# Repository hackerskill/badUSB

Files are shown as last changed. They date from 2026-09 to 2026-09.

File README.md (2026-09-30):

# badUSB
A CH552G powered BadUSB keystroke injection tool that emulates a standard USB keyboard to execute automated payloads.

### A compact usb stick style badUSB based on CH552G.
---
USB stick style device to emulate a keyboard for automating payload execution.

## Features
- CH552G acts as the main microcontroller
- Fast injection speed
- USB A connectivity
- LEDs for visual status and feedback
- Compact USB stick style PCB

---

# Schematics-


# PCB-


## How It Works

1. CH552G emulates a standard keyboard.

2. Depending on code, it either waits for bottom button input or automatically injects the payload coded in it.

3. The upper button in pressed while plugging in to enter programming mode.

# BOM-
| Component Name | Description | Quantity |
| :--- | :--- | :---: |
| **CH552G** | Chipset | 1 |
| **Resistors** | Resistors for Led| 4 |
| **Capacitors** | Capacitors for decoupling | 2 |
| **Leds** | Led for showing status | 3 |
| **Buttons** | Buttons for mode switching | 2 |
| **Custom PCB** | Custom PCB | 1 |

---

**Made by hackerskill**

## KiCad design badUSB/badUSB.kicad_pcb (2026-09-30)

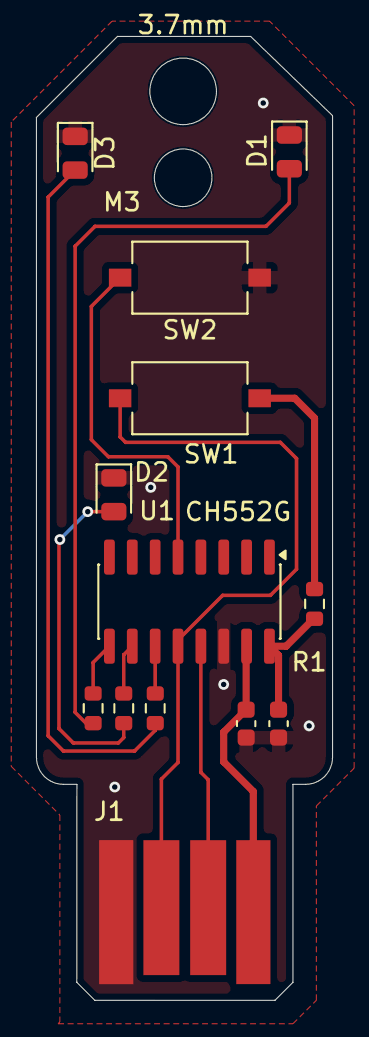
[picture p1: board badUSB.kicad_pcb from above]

Board: 2 copper layers, 16.5 x 53.5 mm, 15 parts (0 on the bottom side), 13 nets.

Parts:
3.7mm: 3.7mm; MountingHole_3.7mm
C1, C2: 100nF; C_0603_1608Metric
D1, D2, D3: LED; LED_0805_2012Metric
J1: USB_A; USB-A
M3: MountingHole_3.2mm_M3
R1: 10k; R_0603_1608Metric
R2, R3, R4: 330R; R_0603_1608Metric
SW1, SW2: SW_Push; SW_Tactile_SPST_NO_Straight_CK_PTS636Sx25SMTRLFS
U1: CH552G; SOIC-16_3.9x9.9mm_P1.27mm

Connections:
+3V3: C2.2, R1.1, U1.16 (3V3)
/D+: J1.3 (D+), SW1.1, U1.12 (P3.6)
/D-: J1.2 (D-), U1.13 (P3.7)
/P1.1: R2.1, U1.9 (P1.1)
/P1.7: SW2.1, U1.5 (P1.7)
/P3.2: R3.1, U1.10 (P3.3)
/P3.4: R4.1, U1.11 (P3.4)
GND: C1.2, C2.1, D1.1 (K), D2.1 (K), D3.1 (K), J1.4 (GND), SW2.2, U1.14 (GND)
unnamed: D1.2 (A), R2.2
unnamed: D2.2 (A), R3.2
unnamed: D3.2 (A), R4.2
unnamed: R1.2, SW1.2
VBUS: C1.1, J1.1 (VBUS), U1.15 (VCC)

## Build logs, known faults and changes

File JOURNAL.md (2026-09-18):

---
title: "badUSB"
author: "hackerskill"
description: "A CH552G powered BadUSB keystroke injection tool that emulates a standard USB keyboard to execute automated payloads."
created_at: "2026-07-27"
---
# badUSB
&#x09;
&#x09;

### Total Hours : 13
---
# Journal 1: Started the project 

**Total time spent: 1 hours**

So for the goal of making a badUSB, a MCU which exposed d- and d+ in a premade module was needed.

Firstly, xiao rp2040 was thought, but then issue with this was same that it didnt expose the d- and d+ and hence would have required tampering, similar issue was with other MCUs also which were easliy available, do finally had to pivot towards the bare chips.

So, decided to use CH552G because of it's availability and not-so-difficult way of usage.



Found the schematics and footprint for this module from official webiste and imported then in kicad.

---

# Journal 2: Schematics work done

**Total time spent: 2.2 hours**

Started off with making the schematics, imported footprint for MCU as well as VBUS, since the USB port would be directly integrated into the device.

After referencing the dataset, figured out that for putting the ch552g in programming port, we have to pull D+ pin high to power source, so made the schematics accordingly.




Also added another button most probably to toggle the payload which can be injected but it might be customised using code later on.



Overall, completed the work for basic schematics needed to start off the pcb.

---

# Journal 3: PCB work started

**Total time spent: 2 hours**

Started the PCB work with placing all the componenents but after rough placement, due to some space remaining, decided to add a couple of leds.





Now need to add these leds back to pcb and place them, along with finishing the tracing work to moving to polishing part, for this referenced some already made pen drives as a inspiration for form factor and overall looks and functionality.

---

# Journal 4: PCB Component Placement

**Total time spent: 2.4 hours**

Read about the the physical need for keeping decoupling capacitors as close as possible and tried to implement the same in the pcb as well.

Kept the resistors for the LEDs also near the MCU only rather than near the LED to optimise for space above the MCU which will have switches and LEDs.




Plan to keep the switches one above the other and 1 led near the MCU and other at the top where hole for making it a keychain can go.

Inital placement took the height of usb stick quite high so tried to refine that and now reduced the overall board length down to around 50mm. Now need to start wiring with traces and finally do a ground pour for various grounds.

---

# Journal 5: PCB Component Wiring

**Total time spent: 3.4 hours**

Started(and almost completed) the wiring for all the componenets in the project, took couple of revisions due to space adjustement and optimisation along with making assembly not highly complex.

Here's how the CH552G looks for now-



Earlier D+ went directly to the USB pad and for the bootloader switch it was branched of in the path, but due to reliability issue with such a method due to docs, the branching was removed and updated design wires D+ directly from pad for both places(the usb pad and pull up push button).




Wires carrying 5V and 3V3 were made thicker than other traces due to better flow of electricity, moreover most of wiring was done on 1st layer only due to SMD nature of componenets except few connections.

---

# Journal 6: Wiring Done and GND pour

**Total time spent: 1.4 hours**

As the wiring work was been completed GND were left so as to be done with GND pour but issue which later appeared-




That the GND pour weren't actually merged but rather due to placement of components getting isolated, and hence to solve this vias were made and connected to GNd pour on other side(Bcu) as well.



Moreover for GND USB, pour was allowed to move more freely to provide strength and stability.

Overall wiring and GND pour work was done, which as mentioned required couple of revisions for taking less space, now need to move to final polish and firmware.

---

# Journal 7: Manufacturing Files Exported and Firmware work

**Total time spent: 0.6 hours**

Manufacturing files for the PCB were exported comprising of gerbers and drill files, along with this library for firmware was also imported and few examples using it will be put in the repository.

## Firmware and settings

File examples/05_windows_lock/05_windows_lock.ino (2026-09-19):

#include "src/userUsbHidKeyboardMouse/USBHIDKeyboardMouse.h"

const int ACTION_BUTTON = 17; 

void setup() {
  USBInit();
  pinMode(ACTION_BUTTON, INPUT_PULLUP);

  delay(200);
}

void loop() {
  if (digitalRead(ACTION_BUTTON) == LOW) {
    Keyboard_press(KEY_LEFT_GUI);       // Using Windows+L Shortcut
    Keyboard_press('l');
    delay(100);
    Keyboard_releaseAll();
    delay(500);
  }
}

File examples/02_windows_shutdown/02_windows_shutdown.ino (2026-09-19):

#include "src/userUsbHidKeyboardMouse/USBHIDKeyboardMouse.h"

const int ACTION_BUTTON = 17;

void setup() {
  USBInit();
  pinMode(ACTION_BUTTON, INPUT_PULLUP);

  while (digitalRead(ACTION_BUTTON) == HIGH) {
    delay(10);
  }

  delay(600);
  Keyboard_press(KEY_LEFT_GUI);
  delay(100);
  Keyboard_press('r');
  delay(100);
  Keyboard_releaseAll();
  delay(600);

  Keyboard_print("shutdown /s /f /t 00");
  delay(100);
  Keyboard_press('\n');
  delay(100);
  Keyboard_releaseAll();
}

void loop() {
}

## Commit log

2026-08-27 schematics work done
    [badUSB.kicad_pcb, badUSB.kicad_sch]
2026-08-27 footprints added
    [badUSB.kicad_sch]
2026-08-28 pcb work
    [badUSB.kicad_pcb, badUSB.kicad_sch]
2026-09-07 pcb work almost done
    [badUSB.kicad_pcb]
2026-09-18 firmware examples
    [badUSB.kicad_pcb]
2026-09-30 make 2 holes
    [badUSB.kicad_pcb]
